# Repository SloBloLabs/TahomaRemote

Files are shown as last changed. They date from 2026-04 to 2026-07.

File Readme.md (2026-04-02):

# Tahoma Remote

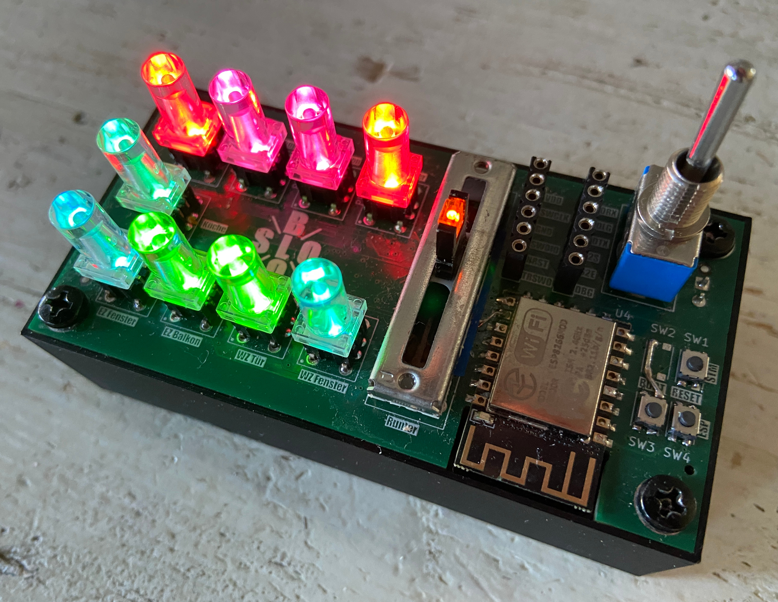
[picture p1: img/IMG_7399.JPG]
image info


## Overview
This device is an internet independent shutter control using the Tahoma Local API. At the same time, it serves as a proof of concept for integration of STM32F405 MCU with an ESP8266 using UART communication and Espressif AT command set.

Both hard and software are tailored to the requirements of my domestic Somfy roller shutter installation, consisting of 9 roller shutters controlled by a Tahoma Switch. The layout of buttons reflect the location of roller shutters looking top down to the flat for easy orientation. Adding/removing shutters to the setup is possible, but may require adaption of both hard and software.

This repository contains all ressources to build the device:
 * the firmware for the STM32 MCU
 * a script to upload ESP AT firmware to the ESP MCU
 * the board's KiCad design
 * a 3D model housing the board

## Operation
 * Switch the device on
 * During the startup sequence, Tahoma Remote
   * initializes communication to ESP
   * sets up WIFI connection
   * fetches current shutter states from Tahoma Switch
 * The button colours reflect the actual shutter closures of each motor in HSV colour space:
   * green = up
   * blue = 50%
   * red = closed
   * and any colour inbetween
 * Choose your target closure amount using the slider pot
 * Hit the buttons of corresponding shutters to execute the target closure command
 * While motors are moving, corresponding buttons are blinking
 * Motor status is updated each 1,5 seconds

## Highlights
As a proof of concept, these are the feature highlights of the project:
 * DMA driven UART communication between STM32F405 and ESP8266
 * Client side implementation of AT command set
 * Using Tahoma Local API. No internet required!
 * JSON stream parsing for memory efficient payload consumption (big up for the great [lwjson](https://github.com/MaJerle/lwjson.git) project!)
 * Highly capable RGB Led driver implementation using DMA, I2C and PCA9685PW driver chips
 * FreeRTOS for independent UI and communication threads
 * All firmware code written in plain C/C++ using STM32 LL (Low Level) API
 * Compact design
 * Battery powered

## Installation Notes
### Flashing ESP Firmware
 1. Install esptool using

        brew install esptool
 2. Go to https://github.com/espressif/esp-at/releases and find the link for the latest ESP8266 compatible AT firmware, such as

    [ESP-WROOM-02-AT-V2.3.0.0.zip](https://dl.espressif.com/esp-at/firmwares/esp8266/ESP-WROOM-02-AT-V2.3.0.0.zip)
 3. Download and extract the file into ESP subfolder.<br>
    Within the "factory" subfolder, the archive will contain the firmware binary file called "factory/factory_WROOM-02.bin"

 4. Connect a USB serial adapter such as FTDI Friend or Arduino Uno

        USB Serial Adapter            Tahoma Remote
                       GND ---------> GND
                        TX ---------> EDTX
                        RX ---------> EDRX

 5. Press and hold the ESP Boot button on Tahoma Remote and switch the device on. Then release the button again.
 6. Go to ESP subfolder and issue uploadATFW.sh script (check and apply correct settings regarding PORT and FWPATH variable!)

        ./uploadATFW.sh

    If the command is not executable, add respective rights to it:

        chmod u+x uploadATFW.sh
    
    The expected output looks something like this:

        esptool v5.1.0
        Connected to ESP8266 on /dev/cu.usbserial-XXX:
        Chip type:          ESP8266EX
        Features:           Wi-Fi, 160MHz
        Crystal frequency:  26MHz
        MAC:                e0:98:06:0a:71:a6
        
        Stub flasher running.
        
        Configuring flash size...
        Flash will be erased from 0x00000000 to 0x001fffff...
        Flash parameters set to 0x0241.
        Wrote 2097152 bytes (582385 compressed) at 0x00000000 in 54.0 seconds (310.8 kbit/s).
        Hash of data verified.
        
        Hard resetting via RTS pin...
    
### Flashing STM32 firmware
 1. Install VS Code
 2. Install STM32Cube Extensions for VS Code
 3. Add lwjson as submodule to the project

        git submodule add https://github.com/MaJerle/lwjson.git
        git submodule update --init
 4. Rename config_example.h to config.h and configure your local credentials and system information:
   * WIFI_SSID: your WIFI SSID
   * WIFI_PASSWD: your WIFI password
   * TAHOMA_HOST: the Tahoma Switch hostname, typically in the form 'gateway-\<box pin code\>.local'
   * TAHOMA_AUTH: the developer token generated within Somfy App
   * shutterConfigTable takes a set of roller shutters in the system (see TahomaManger.h for the structure of ShutterConfig entries)
 5. Configure and build the project using device STM32F405RGT6 and GCC toolchain in VSCode
    
    alternatively, if cmake and ninja are installed on the system, you can run these commands:

        cmake --preset Release
        cmake --build --preset Release
 6. Connect ST-Link to the SWO interface on Tahoma Remote
 7. Flash the firmware: Run and Debug and apply "STM32Cube: STLink GDB Server"

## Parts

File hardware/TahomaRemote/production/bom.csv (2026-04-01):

Designator | Footprint | Quantity | Value | LCSC Part #
BT1 | PinHeader_1x02_P2.54mm_Vertical | 1 | Battery
C1, C10, C12, C15, C16, C17, C18, C2, C21, C22, C23, C24, C25, C26, C4, C5, C6, C7, C8 | 0402 | 19 | 100n | C1525
C11, C29, C30 | 0402 | 3 | 1u | C52923
C19, C20 | 0402 | 2 | 2u2 | C12530
C27, C28, C3 | CP_EIA-3216-18_Kemet-A | 3 | 10u | C7171
C9 | 0402 | 1 | 10n | C15195
FB1 | 0603 | 1 | 120R@100MHz
J1 | PinSocket_1x06_P2.54mm_Vertical | 1 | SWO Connector
J2 | PinSocket_1x06_P2.54mm_Vertical | 1 | Conn_01x06_Socket
PB0, PB1, PB2, PB3, PB4, PB5, PB6, PB7, PB8 | TC002-N11AS2XT-RGB | 9 | TC002-N11AS2XT-RGB
R1, R2 | 0402 | 2 | 4k7 | C25900
R10, R12, R14, R17, R24, R26, R28, R30, R8 | 0402 | 9 | 470 | C25117
R11, R13, R15, R16, R18, R20, R21, R22, R23, R25, R27, R29, R31, R4, R5, R6, R7, R9 | 0402 | 18 | 220 | C25091
R19, R3, R32 | 0402 | 3 | 10k | C25744
R33 | 0402 | 1 | 49.9 | C25120
R35 | 0402 | 1 | 1k | C11702
S1 | Bourns_PTL20 | 1 | Bourns_PTL
SW1 | SW_Push_1P1T_NO_CK_KMR2 | 1 | ST Reset
SW3 | SW_Push_1P1T_NO_CK_KMR2 | 1 | ESP Boot Mode
SW4 | SW_Push_1P1T_NO_CK_KMR2 | 1 | ESP Reset
SW5 | SW_Toggle_MS500 | 1 | Power
U1, U2 | TSSOP-28_4.4x9.7mm_P0.65mm | 2 | PCA9685PW
U3 | LQFP-64_10x10mm_P0.5mm | 1 | STM32F405RGTx
U4 | ESP-12E | 1 | ESP-12F
U5 | TO-252-3_TabPin2 | 1 | LM1117DT-3.3

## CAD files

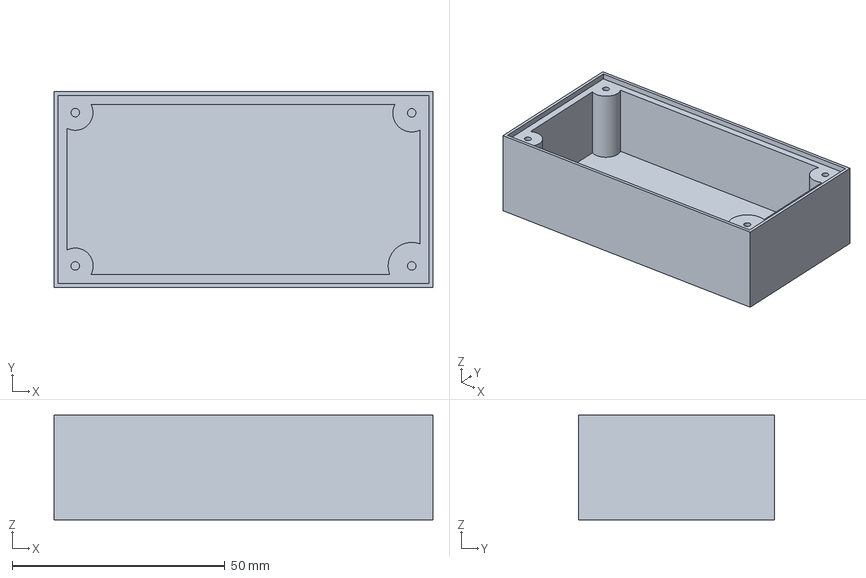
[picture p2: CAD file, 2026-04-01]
hardware/Case/TahomaRemoteCase-Body.3mf
89.0 x 46.0 x 24.6 mm

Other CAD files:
hardware/Case/TahomaRemoteCase.FCStd
hardware/Case/TahomaRemoteCase-Body.stl

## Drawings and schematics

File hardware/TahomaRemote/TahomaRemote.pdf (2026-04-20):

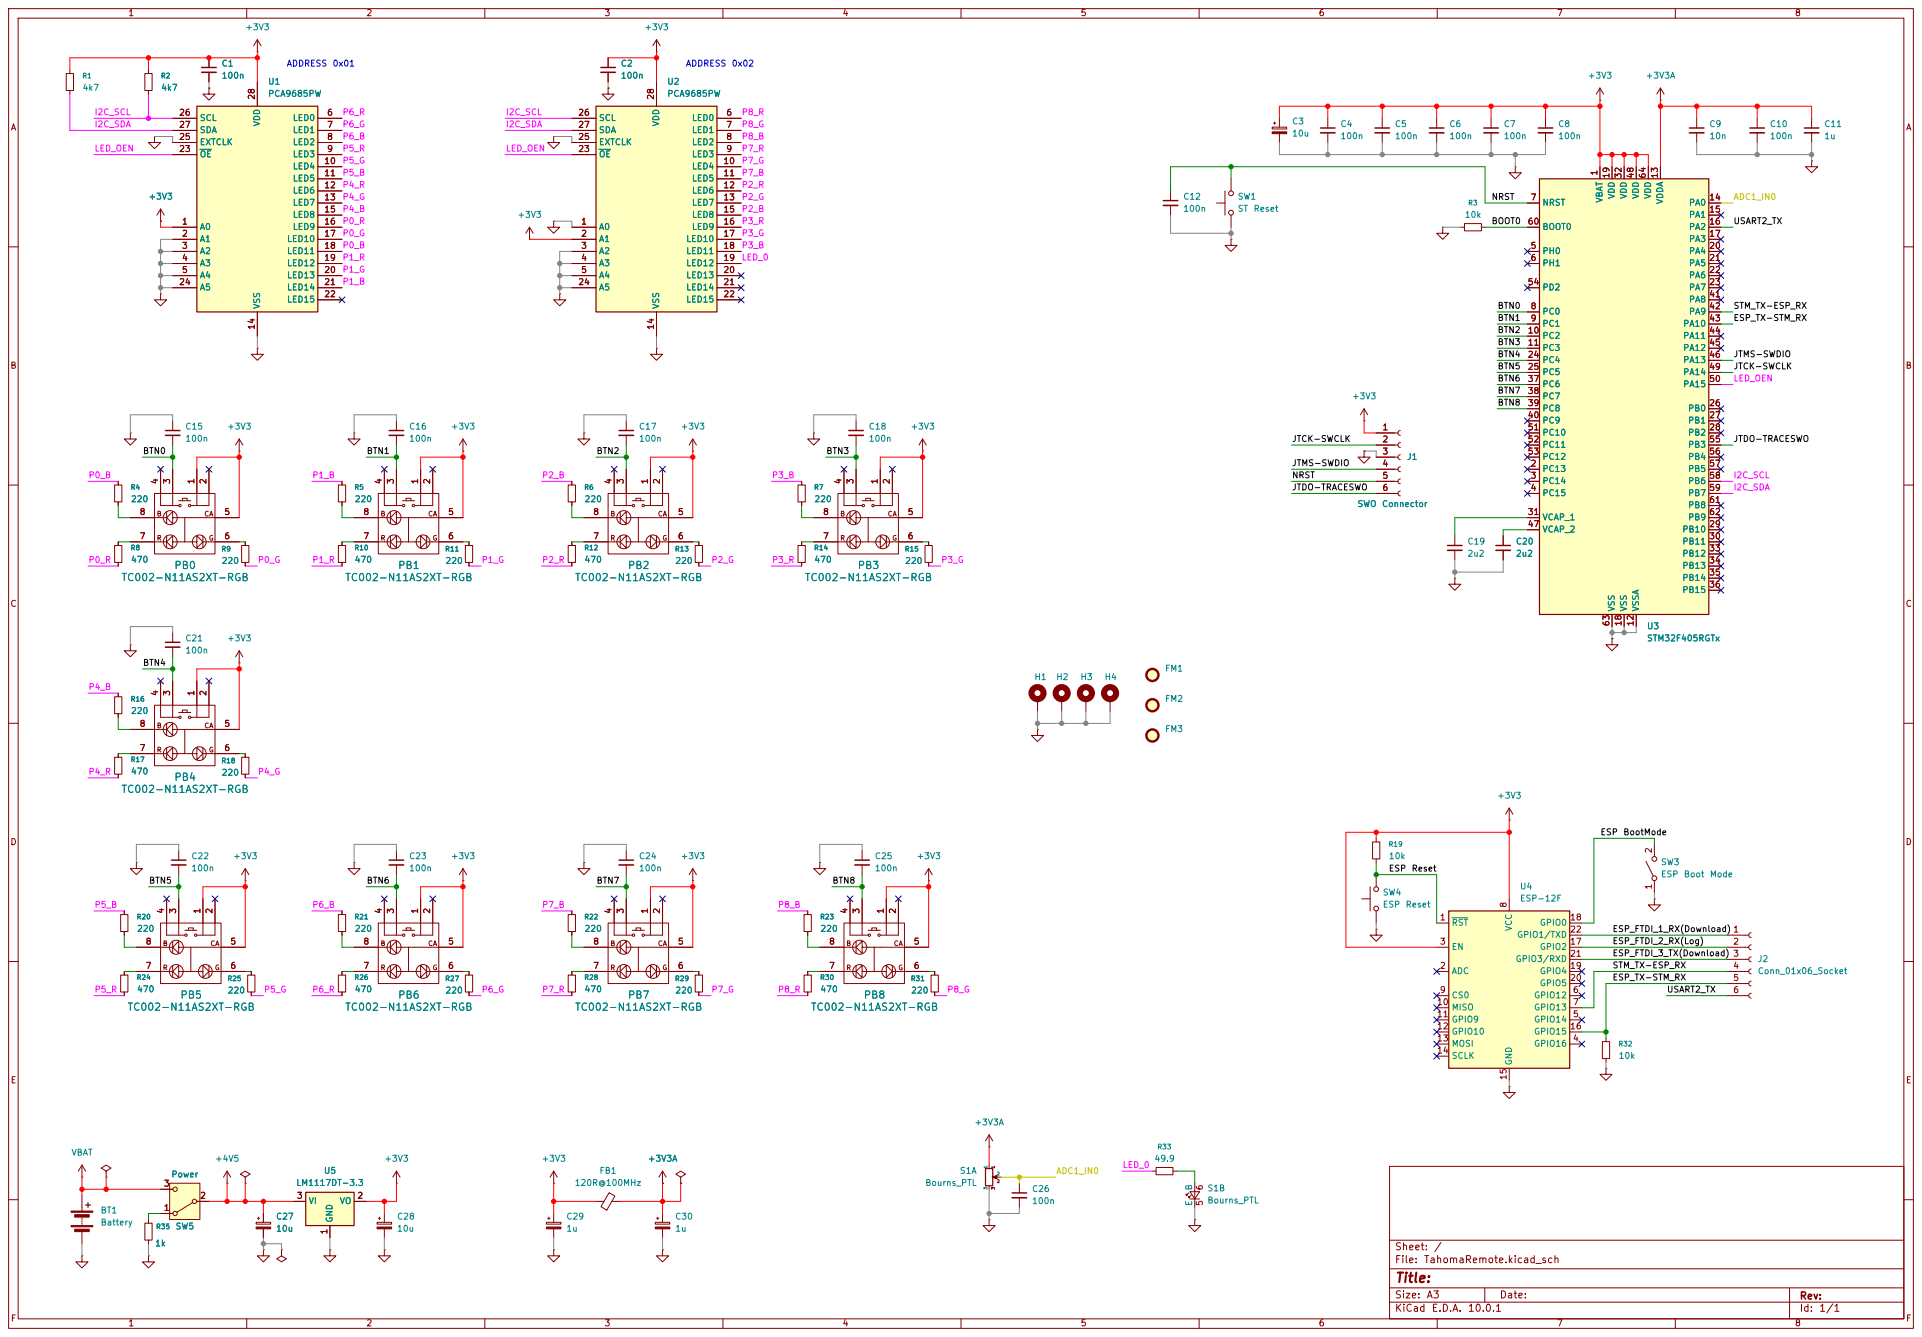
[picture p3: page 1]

Size: A3 | Rev: | F Date:
KiCad E.D.A. 10.0.1 | Id: 1/1

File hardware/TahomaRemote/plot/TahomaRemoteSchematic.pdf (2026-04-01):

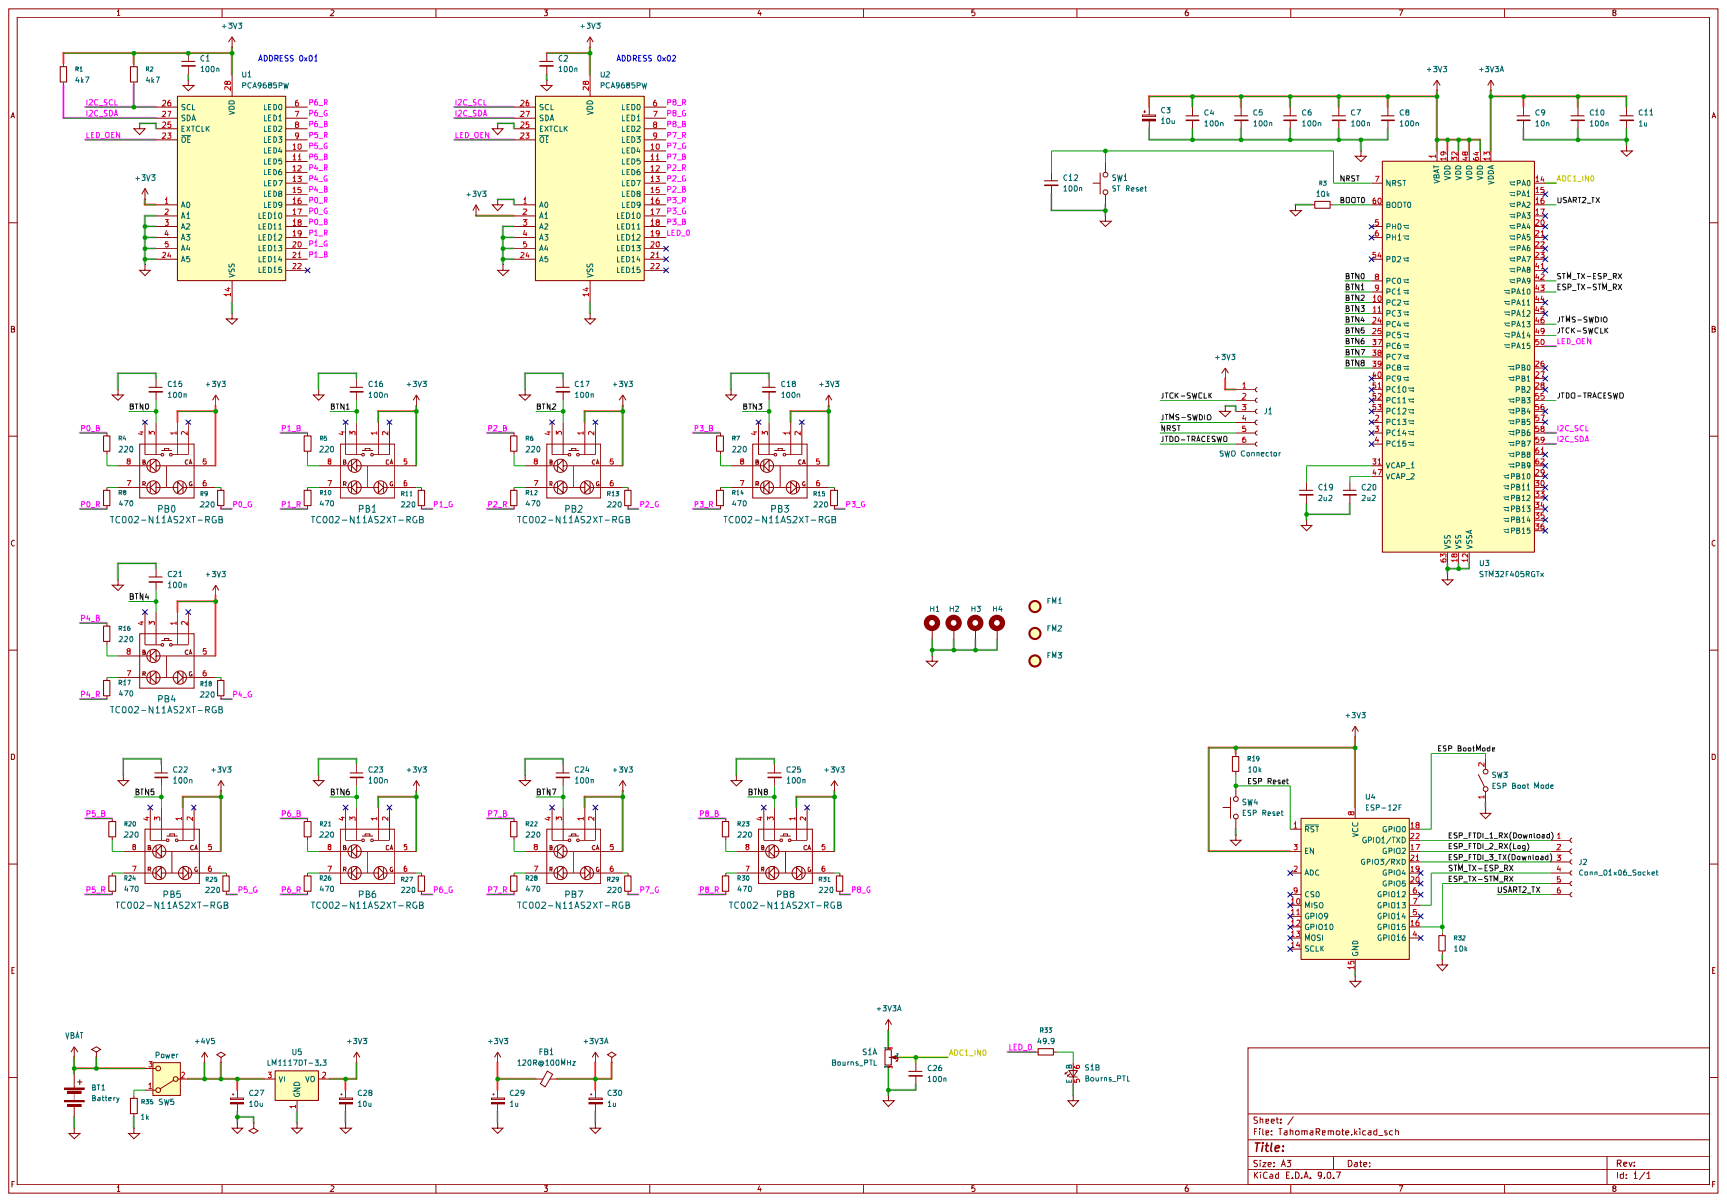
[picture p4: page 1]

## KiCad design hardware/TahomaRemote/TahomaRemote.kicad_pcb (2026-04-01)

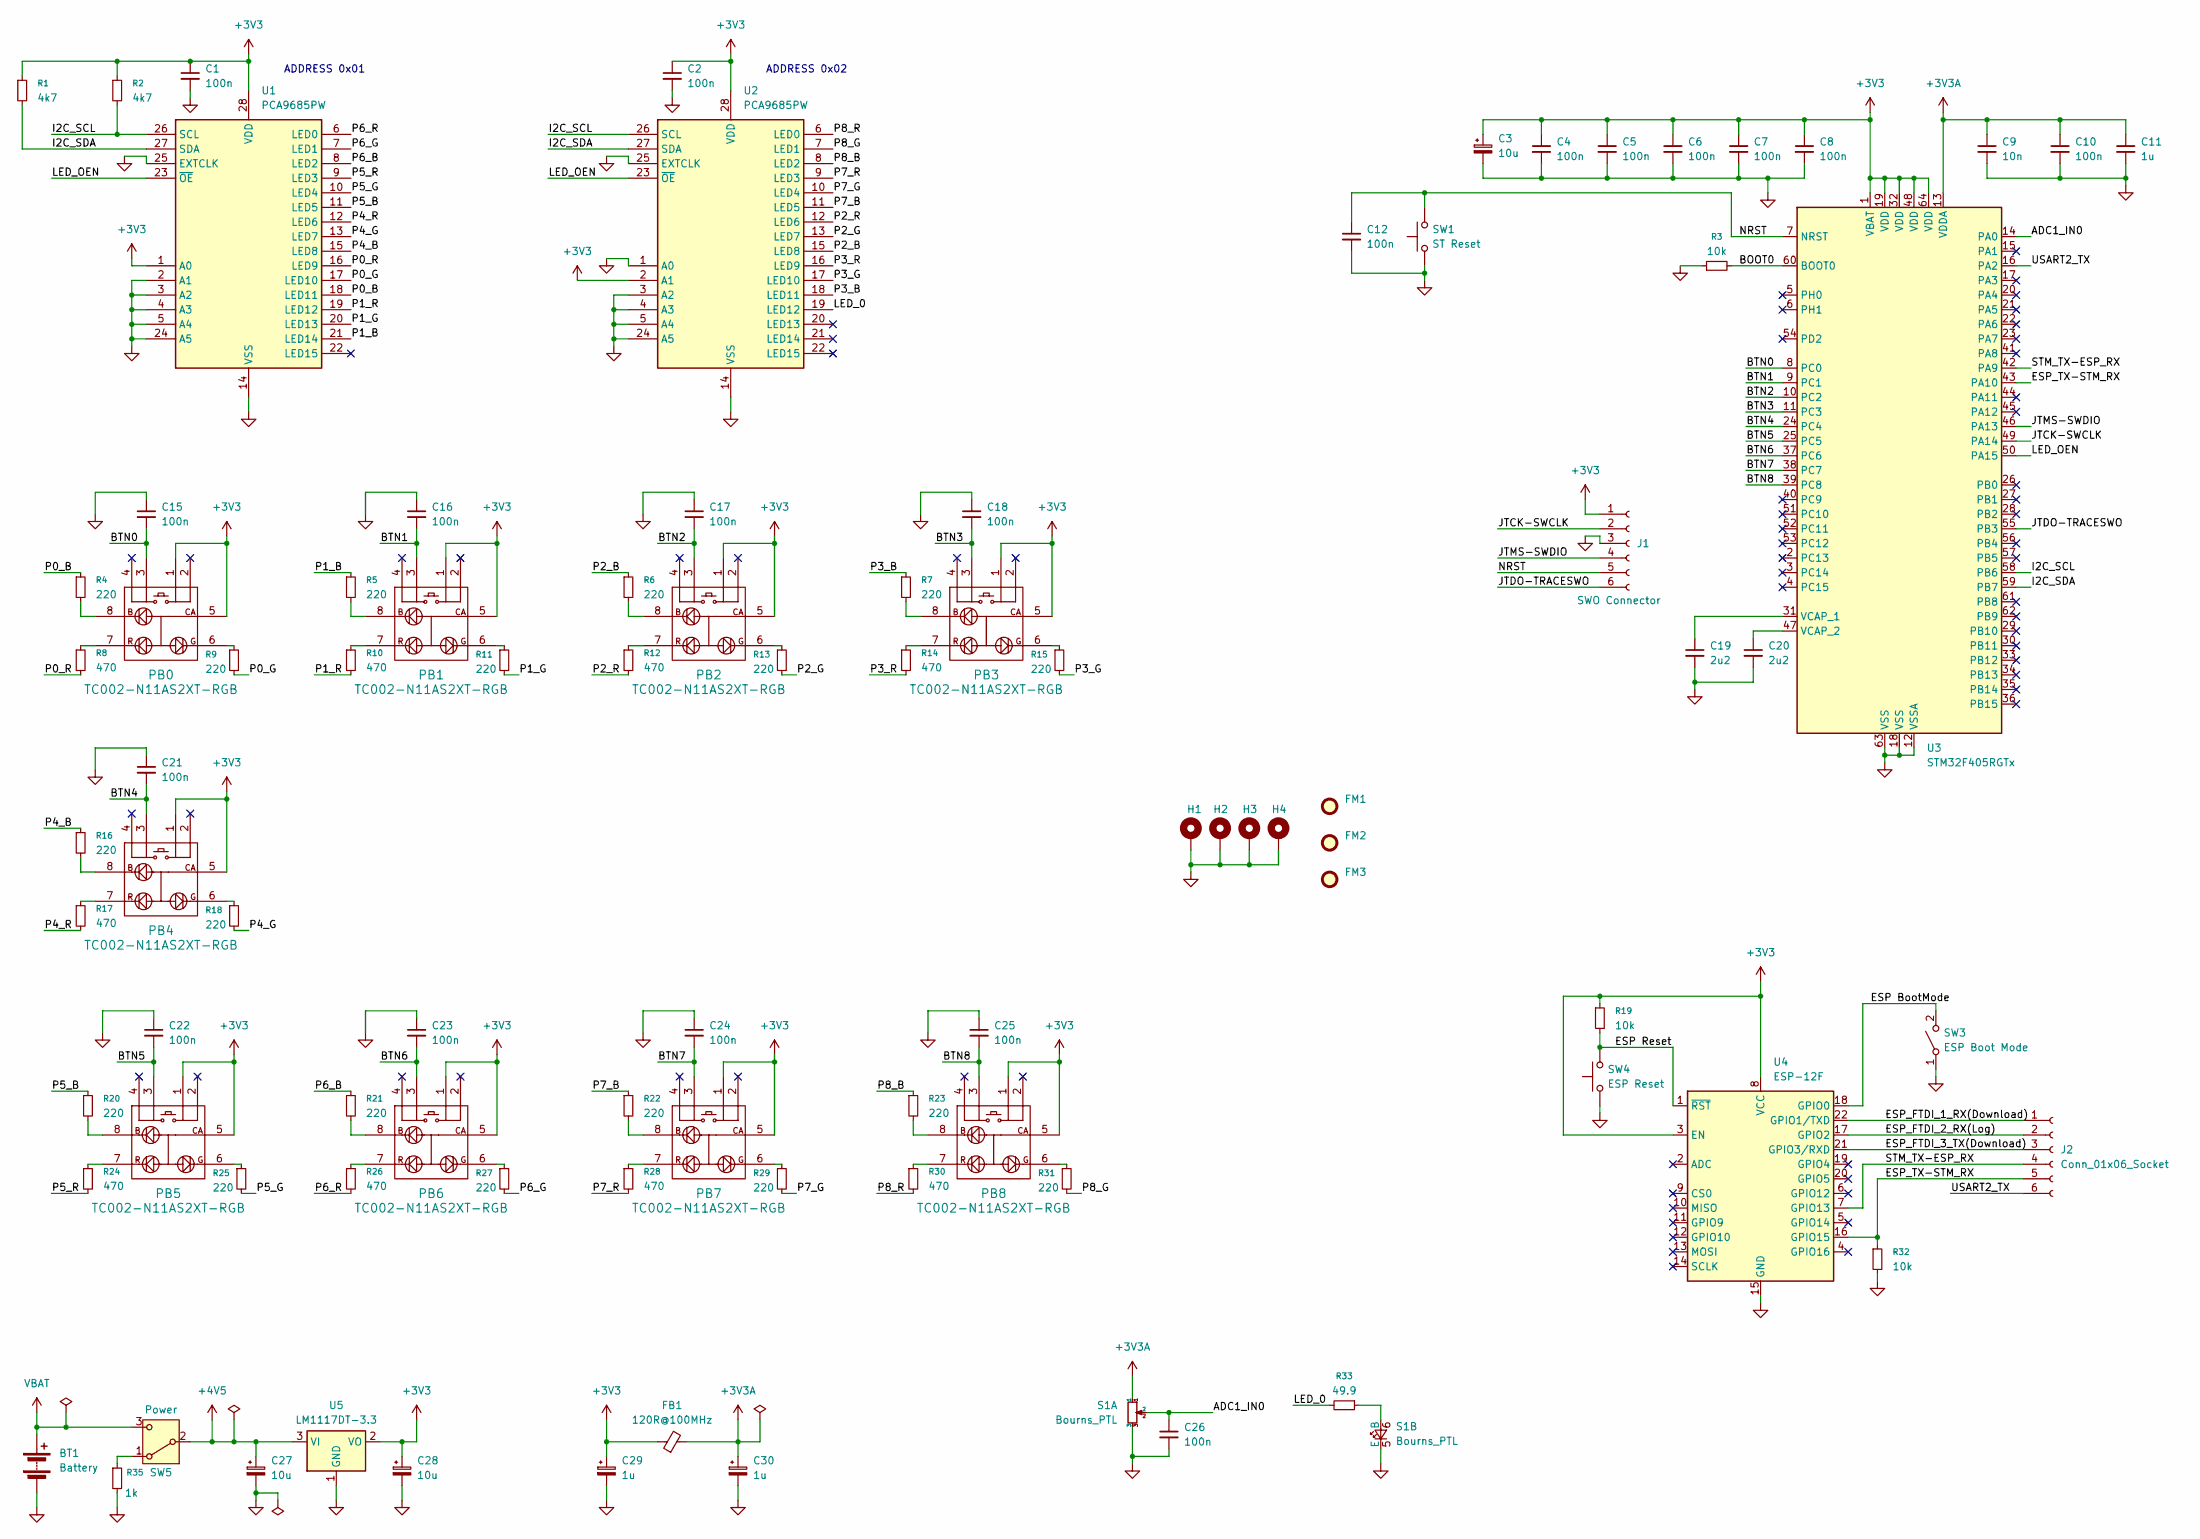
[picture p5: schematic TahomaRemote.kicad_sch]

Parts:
BT1: Battery; PinHeader_1x02_P2.54mm_Vertical
C1, C2, C4, C5, C6, C7, C8, C10, C12, C15, C16, C17, C18, C21, C22, C23, C24, C25, C26: 100n; C_0402_1005Metric; LCSC C1525
C3, C27, C28: 10u; CP_EIA-3216-18_Kemet-A; LCSC C7171
C9: 10n; C_0402_1005Metric; LCSC C15195
C11, C29, C30: 1u; C_0402_1005Metric; LCSC C52923
C19, C20: 2u2; C_0402_1005Metric; LCSC C12530
FB1: 120R@100MHz; L_0603_1608Metric
FM1, FM2, FM3: Fiducial; Fiducial_1mm_Mask2mm
H1, H2, H3, H4: MountingHole_Pad; MountingHole_3.2mm_M3_Pad_Via
J1: SWO Connector; PinSocket_1x06_P2.54mm_Vertical
J2: Conn_01x06_Socket; PinSocket_1x06_P2.54mm_Vertical
PB0, PB1, PB2, PB3, PB4, PB5, PB6, PB7, PB8: TC002-N11AS2XT-RGB
R1, R2: 4k7; R_0402_1005Metric; LCSC C25900
R3, R19, R32: 10k; R_0402_1005Metric; LCSC C25744
R4, R5, R6, R7, R9, R11, R13, R15, R16, R18, R20, R21, R22, R23, R25, R27, R29, R31: 220; R_0402_1005Metric; LCSC C25091
R8, R10, R12, R14, R17, R24, R26, R28, R30: 470; R_0402_1005Metric; LCSC C25117
R33: 49.9; R_0402_1005Metric; LCSC C25120
R35: 1k; R_0402_1005Metric; LCSC C11702
S1: Bourns_PTL; Bourns_PTL20
SW1: ST Reset; SW_Push_1P1T_NO_CK_KMR2
SW3: ESP Boot Mode; SW_Push_1P1T_NO_CK_KMR2
SW4: ESP Reset; SW_Push_1P1T_NO_CK_KMR2
SW5: Power; SW_Toggle_MS500
U1, U2: PCA9685PW; TSSOP-28_4.4x9.7mm_P0.65mm
U3: STM32F405RGTx; LQFP-64_10x10mm_P0.5mm
U4: ESP-12F; ESP-12E
U5: LM1117DT-3.3; TO-252-3_TabPin2

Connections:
+3V3: C1.1, C2.1, C3.1, C4.1, C5.1, C6.1, C7.1, C8.1, C28.1, C29.1, FB1.1, J1.1, PB0.1 (UP-A), PB0.5 (CA), PB1.1 (UP-A), PB1.5 (CA), PB2.1 (UP-A), PB2.5 (CA), PB3.1 (UP-A), PB3.5 (CA), PB4.1 (UP-A), PB4.5 (CA), PB5.1 (UP-A), PB5.5 (CA), PB6.1 (UP-A), PB6.5 (CA), PB7.1 (UP-A), PB7.5 (CA), PB8.1 (UP-A), PB8.5 (CA), R1.1, R2.1, R19.1, U1.1 (A0), U1.28 (VDD), U2.2 (A1), U2.28 (VDD), U3.1 (VBAT), U3.19 (VDD), U3.32 (VDD), U3.48 (VDD), U3.64 (VDD), U4.3 (EN), U4.8 (VCC), U5.2 (VO)
+3V3A: C9.1, C10.1, C11.1, C30.1, FB1.2, S1.1, U3.13 (VDDA)
+4V5: C27.1, SW5.2 (B), U5.3 (VI)
/ADC1_IN0: C26.1, S1.2, U3.14 (PA0)
/BOOT0: R3.2, U3.60 (BOOT0)
/BTN0: C15.2, PB0.3 (DOWN-A), U3.8 (PC0)
/BTN1: C16.2, PB1.3 (DOWN-A), U3.9 (PC1)
/BTN2: C17.2, PB2.3 (DOWN-A), U3.10 (PC2)
/BTN3: C18.2, PB3.3 (DOWN-A), U3.11 (PC3)
/BTN4: C21.2, PB4.3 (DOWN-A), U3.24 (PC4)
/BTN5: C22.2, PB5.3 (DOWN-A), U3.25 (PC5)
/BTN6: C23.2, PB6.3 (DOWN-A), U3.37 (PC6)
/BTN7: C24.2, PB7.3 (DOWN-A), U3.38 (PC7)
/BTN8: C25.2, PB8.3 (DOWN-A), U3.39 (PC8)
/ESP BootMode: SW3.2 (B), U4.18 (GPIO0)
/ESP Reset: R19.2, SW4.2, U4.1 (~RST)
/ESP_FTDI_1_RX(Download): J2.1, U4.22 (GPIO1/TXD)
/ESP_FTDI_2_RX(Log): J2.2, U4.17 (GPIO2)
/ESP_FTDI_3_TX(Download): J2.3, U4.21 (GPIO3/RXD)
/ESP_TX-STM_RX: J2.5, R32.1, U3.43 (PA10), U4.16 (GPIO15)
/I2C_SCL: R2.2, U1.26 (SCL), U2.26 (SCL), U3.58 (PB6)
/I2C_SDA: R1.2, U1.27 (SDA), U2.27 (SDA), U3.59 (PB7)
/JTCK-SWCLK: J1.2, U3.49 (PA14)
/JTDO-TRACESWO: J1.6, U3.55 (PB3)
/JTMS-SWDIO: J1.4, U3.46 (PA13)
/LED_0: R33.2, U2.19 (LED12)
/LED_OEN: U1.23 (~OE), U2.23 (~OE), U3.50 (PA15)
/NRST: C12.1, J1.5, SW1.2, U3.7 (NRST)
/P0_B: R4.1, U1.18 (LED11)
/P0_G: R9.2, U1.17 (LED10)
/P0_R: R8.2, U1.16 (LED9)
/P1_B: R5.1, U1.21 (LED14)
/P1_G: R11.2, U1.20 (LED13)
/P1_R: R10.2, U1.19 (LED12)
/P2_B: R6.1, U2.15 (LED8)
/P2_G: R13.2, U2.13 (LED7)
/P2_R: R12.2, U2.12 (LED6)
/P3_B: R7.1, U2.18 (LED11)
/P3_G: R15.2, U2.17 (LED10)
/P3_R: R14.2, U2.16 (LED9)
/P4_B: R16.1, U1.15 (LED8)
/P4_G: R18.2, U1.13 (LED7)
/P4_R: R17.2, U1.12 (LED6)
/P5_B: R20.1, U1.11 (LED5)
/P5_G: R25.2, U1.10 (LED4)
/P5_R: R24.2, U1.9 (LED3)
/P6_B: R21.1, U1.8 (LED2)
/P6_G: R27.2, U1.7 (LED1)
/P6_R: R26.2, U1.6 (LED0)
/P7_B: R22.1, U2.11 (LED5)
/P7_G: R29.2, U2.10 (LED4)
/P7_R: R28.2, U2.9 (LED3)
/P8_B: R23.1, U2.8 (LED2)
/P8_G: R31.2, U2.7 (LED1)
/P8_R: R30.2, U2.6 (LED0)
/STM_TX-ESP_RX: J2.4, U3.42 (PA9), U4.7 (GPIO13)
/USART2_TX: J2.6, U3.16 (PA2)
GND: BT1.2 (-), C1.2, C2.2, C3.2, C4.2, C5.2, C6.2, C7.2, C8.2, C9.2, C10.2, C11.2, C12.2, C15.1, C16.1, C17.1, C18.1, C19.2, C20.2, C21.1, C22.1, C23.1, C24.1, C25.1, C26.2, C27.2, C28.2, C29.2, C30.2, H1.1, H2.1, H3.1, H4.1, J1.3, R3.1, R32.2, R35.2, S1.3, S1.5 (E), SW1.1, SW3.1 (A), SW4.1, U1.2 (A1), U1.3 (A2), U1.4 (A3), U1.5 (A4), U1.14 (VSS), U1.24 (A5), U1.25 (EXTCLK), U2.1 (A0), U2.3 (A2), U2.4 (A3), U2.5 (A4), U2.14 (VSS), U2.24 (A5), U2.25 (EXTCLK), U3.12 (VSSA), U3.18 (VSS), U3.63 (VSS), U4.15 (GND), U5.1 (GND)
unnamed: PB0.8 (B), R4.2
unnamed: PB0.6 (G), R9.1
unnamed: PB0.7 (R), R8.1
unnamed: PB1.8 (B), R5.2
unnamed: PB1.6 (G), R11.1
unnamed: PB1.7 (R), R10.1
unnamed: PB2.8 (B), R6.2
unnamed: PB2.6 (G), R13.1
unnamed: PB2.7 (R), R12.1
unnamed: PB3.8 (B), R7.2
unnamed: PB3.6 (G), R15.1
unnamed: PB3.7 (R), R14.1
unnamed: PB4.8 (B), R16.2
unnamed: PB4.6 (G), R18.1
unnamed: PB4.7 (R), R17.1
unnamed: PB5.8 (B), R20.2
unnamed: PB5.6 (G), R25.1
unnamed: PB5.7 (R), R24.1
unnamed: PB6.8 (B), R21.2
unnamed: PB6.6 (G), R27.1
unnamed: PB6.7 (R), R26.1
unnamed: PB7.8 (B), R22.2
unnamed: PB7.6 (G), R29.1
unnamed: PB7.7 (R), R28.1
unnamed: PB8.8 (B), R23.2
unnamed: PB8.6 (G), R31.1
unnamed: PB8.7 (R), R30.1
unnamed: R33.1, S1.6 (B)
unnamed: R35.1, SW5.1 (A)
unnamed: C19.1, U3.31 (VCAP_1)
unnamed: C20.1, U3.47 (VCAP_2)
VBAT: BT1.1 (+), SW5.3 (C)

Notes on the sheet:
ADDRESS 0x01
ADDRESS 0x02

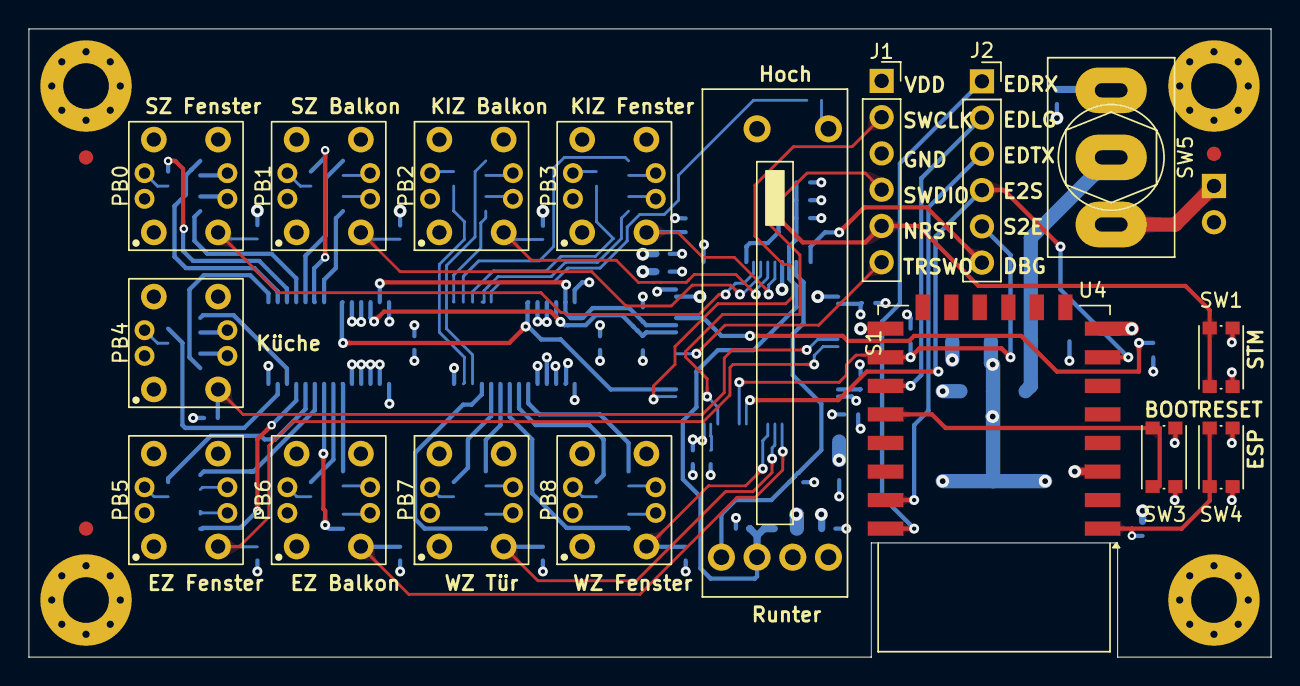
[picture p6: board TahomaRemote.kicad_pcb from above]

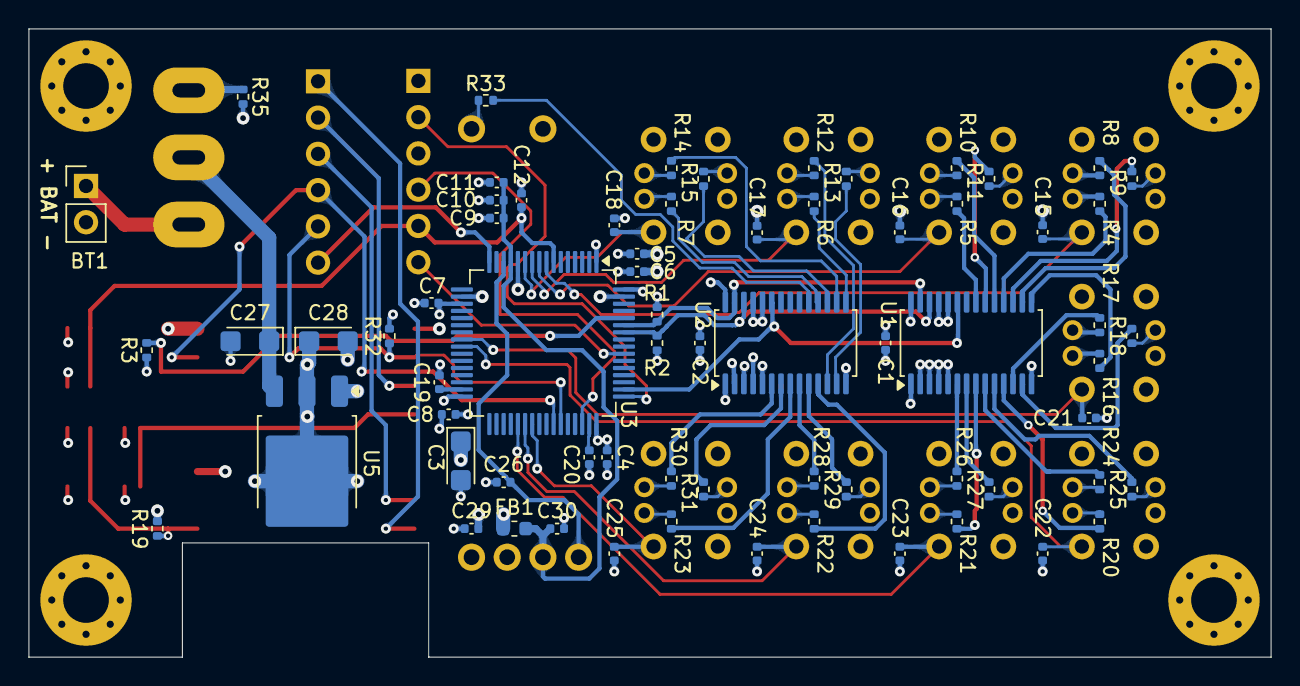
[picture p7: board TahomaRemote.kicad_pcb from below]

Board: 4 copper layers, 87.0 x 44.0 mm, 92 parts (68 on the bottom side), 90 nets.

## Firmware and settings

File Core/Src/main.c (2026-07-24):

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
/* Includes ------------------------------------------------------------------*/
#include "main.h"
#include "cmsis_os.h"
#include "adc.h"
#include "dma.h"
#include "i2c.h"
#include "usart.h"
#include "gpio.h"

/* USER CODE BEGIN Includes */
#include "Dbg.h"
/* USER CODE END Includes */

/* USER CODE BEGIN PD */
#define ESP_UART USART1
#define ESP_DMA DMA2
#define ESP_RX_DMA_STREAM LL_DMA_STREAM_5
#define ESP_TX_DMA_STREAM LL_DMA_STREAM_7
/* USER CODE END PD */


/* USER CODE BEGIN PV */
/* Buffer used for transmission */
#define RX_BUFFER_SIZE 1024
char rxBuffer[RX_BUFFER_SIZE];
volatile size_t readPtr = 0;
volatile size_t writePtr = 0;

#define TX_BUFFER_SIZE 1024
char txBuffer[TX_BUFFER_SIZE];
volatile uint8_t transmissionComplete = 1;

// Signaled from the UART RX ISR (USART idle-line / DMA half-transfer / DMA
// transfer-complete) whenever new bytes may be available. Lets nextChar()
// block briefly instead of busy-spinning while waiting for the ESP8266.
static osSemaphoreId_t rxDataSem = NULL;
/* USER CODE END PV */

void SystemClock_Config(void);
void MX_FREERTOS_Init(void);
/* USER CODE BEGIN PFP */
void     setupDMA(void);
int      StartTransfers(void);
uint8_t  Buffercmp8(uint8_t* pBuffer1, uint8_t* pBuffer2, uint8_t BufferLength);
/* USER CODE END PFP */

/**
  * @brief  The application entry point.
  * @retval int
  */
int main(void)
{

  /* MCU Configuration--------------------------------------------------------*/

  /* Reset of all peripherals, Initializes the Flash interface and the Systick. */
  HAL_Init();

  /* Configure the system clock */
  SystemClock_Config();

  /* Initialize all configured peripherals */
  MX_GPIO_Init();
  MX_DMA_Init();
  MX_USART1_UART_Init();
  MX_USART2_UART_Init();
  MX_ADC1_Init();
  MX_I2C1_Init();
  /* USER CODE BEGIN 2 */
  setupDMA();
  /* USER CODE END 2 */

  /* Init scheduler */
  osKernelInitialize();  /* Call init function for freertos objects (in cmsis_os2.c) */
  MX_FREERTOS_Init();

  /* Start scheduler */
  osKernelStart();

  /* We should never get here as control is now taken by the scheduler */

  /* Infinite loop */
  /* USER CODE BEGIN WHILE */
  while (1)
  {
    /* USER CODE END WHILE */

    /* USER CODE BEGIN 3 */
  }
  /* USER CODE END 3 */
}

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
/* USER CODE BEGIN 4 */
void setupDMA() {

  // Enable RX interrupts (HT, TC, Usart IDLE)
  LL_DMA_EnableIT_HT(ESP_DMA, ESP_RX_DMA_STREAM);
  LL_DMA_EnableIT_TC(ESP_DMA, ESP_RX_DMA_STREAM);
  LL_USART_EnableIT_IDLE(ESP_UART);

  // Enable DMA TX TC interrupts
  LL_DMA_EnableIT_TC(ESP_DMA, ESP_TX_DMA_STREAM);

  // Configure TX DMA
  LL_DMA_SetPeriphAddress(ESP_DMA, ESP_TX_DMA_STREAM, LL_USART_DMA_GetRegAddr(USART1));

  // start DMA reception
  LL_DMA_SetPeriphAddress(ESP_DMA, ESP_RX_DMA_STREAM, LL_USART_DMA_GetRegAddr(USART1));
  LL_DMA_SetMemoryAddress(ESP_DMA, ESP_RX_DMA_STREAM, (uint32_t)rxBuffer);
  LL_DMA_SetDataLength(ESP_DMA, ESP_RX_DMA_STREAM, sizeof(rxBuffer));
  LL_USART_EnableDMAReq_RX(ESP_UART);
  //LL_USART_ClearFlag_TC(USART1);
  LL_DMA_EnableStream(ESP_DMA, ESP_RX_DMA_STREAM);

}

void sendCommand(const char* buf, size_t len) {
  TRACE_LOG("sendCommand: %.*s with length %d\n", len, buf, len);
  if(len >= TX_BUFFER_SIZE) {
    USER_LOG("Command too long for TR Buffer %d", len);
    return;
  }
  
  while(transmissionComplete != 1);
  memcpy(txBuffer, buf, len);

  // DMA transfer
  LL_DMA_SetMemoryAddress(ESP_DMA, ESP_TX_DMA_STREAM, (uint32_t)txBuffer);
  LL_DMA_SetDataLength(ESP_DMA, ESP_TX_DMA_STREAM, len);
  LL_USART_EnableDMAReq_TX(ESP_UART);
  LL_USART_ClearFlag_TC(ESP_UART);
  LL_DMA_EnableStream(ESP_DMA, ESP_TX_DMA_STREAM);
  transmissionComplete = 0;
}

size_t available() {
  if(writePtr >= readPtr) {
    return writePtr - readPtr;
  } else {
    return (sizeof(rxBuffer) - readPtr) + writePtr;
  }
}

void uartRxSemInit(void) {
  rxDataSem = osSemaphoreNew(1, 0, NULL);
}

char nextChar() {
  if(!available()) {
    // Block briefly for new data instead of busy-spinning; rxDataSem is
    // released by uartRxCallback() when the ISR observes new bytes. Bounded
    // wait keeps callers' own timeout/elapsed-time checks working as before.
    if(rxDataSem != NULL) {
      osSemaphoreAcquire(rxDataSem, 500);
    }
    if(!available()) {
      return 0;
    }
  }
  char c = rxBuffer[readPtr++];
  if(readPtr == RX_BUFFER_SIZE) {
    readPtr = 0;
  }
  return c;
}

void uartRxCallback() {
  writePtr = sizeof(rxBuffer) - LL_DMA_GetDataLength(DMA2, LL_DMA_STREAM_5);
  if(rxDataSem != NULL) {
    osSemaphoreRelease(rxDataSem);
  }
}

void uartTxCompleteCallback() {
  transmissionComplete = 1;
}
/* USER CODE END 4 */

/**
  * @brief  Period elapsed callback in non blocking mode
  * @note   This function is called  when TIM1 interrupt took place, inside
  * HAL_TIM_IRQHandler(). It makes a direct call to HAL_IncTick() to increment
  * a global variable "uwTick" used as application time base.
  * @param  htim : TIM handle
  * @retval None
  */
void HAL_TIM_PeriodElapsedCallback(TIM_HandleTypeDef *htim)
{
  if (htim->Instance == TIM1)
  {
    HAL_IncTick();
  }
}

/**
  * @brief  This function is executed in case of error occurrence.
  * @retval None
  */
void Error_Handler(void)
{
  /* USER CODE BEGIN Error_Handler_Debug */
  /* User can add his own implementation to report the HAL error return state */
  __disable_irq();
  while (1)
  {
  }
  /* USER CODE END Error_Handler_Debug */
}
#ifdef USE_FULL_ASSERT
/**
  * @brief  Reports the name of the source file and the source line number
  *         where the assert_param error has occurred.
  * @param  file: pointer to the source file name
  * @param  line: assert_param error line source number
  * @retval None
  */
void assert_failed(uint8_t *file, uint32_t line)
{
  /* USER CODE BEGIN 6 */
  /* User can add his own implementation to report the file name and line number,
     ex: printf("Wrong parameters value: file %s on line %d\r\n", file, line) */
  /* USER CODE END 6 */
}
#endif /* USE_FULL_ASSERT */

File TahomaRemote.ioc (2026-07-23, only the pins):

Mcu.UserName=STM32F405RGTx
PA0-WKUP.Signal=ADCx_IN0
PA10.Signal=USART1_RX
PA13.Signal=SYS_JTMS-SWDIO
PA14.Signal=SYS_JTCK-SWCLK
PA15.GPIO_Label=LED_OEN
PA15.Signal=GPIO_Output
PA2.Signal=USART2_TX
PA3.GPIO_Label=LED
PA3.Signal=GPIO_Output
PA9.Signal=USART1_TX
PB3.Signal=SYS_JTDO-SWO
PB6.Signal=I2C1_SCL
PB7.Signal=I2C1_SDA
PC0.GPIO_Label=BTN0
PC0.Signal=GPXTI0
PC1.GPIO_Label=BTN1
PC1.Signal=GPXTI1
PC2.GPIO_Label=BTN2
PC2.Signal=GPXTI2
PC3.GPIO_Label=BTN3
PC3.Signal=GPXTI3
PC4.GPIO_Label=BTN4
PC4.Signal=GPXTI4
PC5.GPIO_Label=BTN5
PC5.Signal=GPXTI5
PC6.GPIO_Label=BTN6
PC6.Signal=GPXTI6
PC7.GPIO_Label=BTN7
PC7.Signal=GPXTI7
PC8.GPIO_Label=BTN8
PC8.Signal=GPXTI8
PH0-OSC_IN.Signal=RCC_OSC_IN
PH1-OSC_OUT.Signal=RCC_OSC_OUT

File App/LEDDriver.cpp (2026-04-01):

#include "LEDDriver.h"
#include "System.h"
#include "math.h"
#include "Dbg.h"
#include "Utils.h"
#include "cmsis_os2.h"

#define USE_DMA    1
#define LED_I2C    I2C1
#define DMA_STREAM LL_DMA_STREAM_6

// http://stefanfrings.de/stm32/stm32f1.html#i2c
// https://community.st.com/s/question/0D50X00009bLPuwSAG/busy-bus-after-i2c-reading

void LEDDriver::init() {
    //LL_I2C_Enable(LED_I2C); // -> already called by LL_I2C_Init

    if(USE_DMA) {
        //LL_I2C_EnableIT_EVT(LED_I2C);
        //LL_I2C_EnableIT_ERR(LED_I2C);

        LL_DMA_DisableStream(DMA1, DMA_STREAM);
    }

    _chipAddressArray = {1, 2};

    _ledTypeArray[0] = {
        COMMON_ANODE,
        COMMON_ANODE,
        COMMON_ANODE,
        COMMON_ANODE,
        COMMON_ANODE,
        COMMON_ANODE,
        COMMON_ANODE,
        COMMON_ANODE,
        COMMON_ANODE,
        COMMON_ANODE,
        COMMON_ANODE,
        COMMON_ANODE,
        COMMON_ANODE,
        COMMON_ANODE,
        COMMON_ANODE,
        EMPTY};
    
    _ledTypeArray[1] = {
        COMMON_ANODE,
        COMMON_ANODE,
        COMMON_ANODE,
        COMMON_ANODE,
        COMMON_ANODE,
        COMMON_ANODE,
        COMMON_ANODE,
        COMMON_ANODE,
        COMMON_ANODE,
        COMMON_ANODE,
        COMMON_ANODE,
        COMMON_ANODE,
        COMMON_CATHODE,
        EMPTY,
        EMPTY,
        EMPTY};
    
    _transmissionBusy = 0;
    _curChip = 0;

    for(uint32_t chip = 0; chip < NUM_PWM_LED_CHIPS; ++chip) {
        resetChip(chip);
    }
    
    clear();

    // Tie to ground! Disabling brings common cathode LEDs full on.
    ledEnable();
}

void LEDDriver::process() {
    if(_transmissionBusy) {
        return;
    }

    //_pwmLeds[0][0][LED_ON] = 0xFFF; // LED 1 RED
    //_pwmLeds[0][0][LED_OFF] = 0x1000; // LED 1 RED
    //_pwmLeds[0][1][LED_OFF] = 0x0FFF; // LED 1 GREEN
    //_pwmLeds[0][2][LED_OFF] = 0x0FFF; // LED 1 BLUE
    //_pwmLeds[0][3][LED_OFF] = 0x0FFF; // LED 2 RED
    //_pwmLeds[0][4][LED_OFF] = 0x0FFF; // LED 2 GREEN
    //_pwmLeds[0][5][LED_OFF] = 0x0FFF; // LED 2 BLUE
    //_pwmLeds[0][6][LED_OFF] = 0x0FFF; // LED 3 RED
    //_pwmLeds[0][7][LED_OFF] = 0x0FFF; // LED 3 GREEN
    //_pwmLeds[0][8][LED_OFF] = 0x0FFF; // LED 3 BLUE
    //_pwmLeds[0][9][LED_OFF] = 0x0FFF; // LED 4 RED
    //_pwmLeds[0][10][LED_OFF] = 0x0FFF; // LED 4 GREEN
    //_pwmLeds[0][11][LED_OFF] = 0x0FFF; // LED 4 BLUE
    //_pwmLeds[0][12][LED_ON] = 0x1000; // LED 5 RED
    //_pwmLeds[0][12][LED_OFF] = 0xFFF; // LED 5 RED
    //_pwmLeds[0][13][LED_ON] = 0x1FFF; // LED 5 GREEN
    //_pwmLeds[0][13][LED_OFF] = 0x0; // LED 5 GREEN
    //_pwmLeds[0][14][LED_ON] = 0x1FFF; // LED 5 BLUE
    //_pwmLeds[0][14][LED_OFF] = 0x0; // LED 5 BLUE
    //_pwmLeds[0][15][LED_OFF] = 0x0FFF; // EMPTY
    //_pwmLeds[1][0][LED_ON] = 0x1FFF; // LED 6 RED
    //_pwmLeds[1][0][LED_OFF] = 0x0; // LED 6 RED
    //_pwmLeds[1][1][LED_ON] = 0x1FFF; // LED 6 GREEN
    //_pwmLeds[1][1][LED_OFF] = 0x0; // LED 6 GREEN
    //_pwmLeds[1][2][LED_ON] = 0x1FFF; // LED 6 BLUE
    //_pwmLeds[1][2][LED_OFF] = 0x0; // LED 6 BLUE
    //_pwmLeds[1][3][LED_ON] = 0x1FFF; // LED 7 RED
    //_pwmLeds[1][3][LED_OFF] = 0x0; // LED 7 RED
    //_pwmLeds[1][4][LED_ON] = 0x1FFF; // LED 7 GREEN
    //_pwmLeds[1][4][LED_OFF] = 0x0; // LED 7 GREEN
    //_pwmLeds[1][5][LED_ON] = 0x1FFF; // LED 7 BLUE
    //_pwmLeds[1][5][LED_OFF] = 0x0; // LED 7 BLUE
    //_pwmLeds[1][6][LED_ON] = 0x1FFF; // LED 8 RED
    //_pwmLeds[1][6][LED_OFF] = 0x0; // LED 8 RED
    //_pwmLeds[1][7][LED_ON] = 0x1FFF; // LED 8 GREEN
    //_pwmLeds[1][7][LED_OFF] = 0x0; // LED 8 GREEN
    //_pwmLeds[1][8][LED_ON] = 0x1FFF; // LED 8 BLUE
    //_pwmLeds[1][8][LED_OFF] = 0x0; // LED 8 BLUE

    if(USE_DMA) {
        _curChip = 0;
        _transmissionBusy = 1;
        writeRegistersDMA(_curChip, PCA9685_LED0, reinterpret_cast<uint8_t*>(_pwmLeds[_curChip]), 15 << 2);
    } else {
        ErrorStatus status;
        for(_curChip = 0; _curChip < NUM_PWM_LED_CHIPS; ++_curChip) {
            status = writeRegisters(_curChip, PCA9685_LED0, reinterpret_cast<uint8_t*>(_pwmLeds[_curChip]), 15 << 2);
            if(status == ERROR) {
                DEBUG_LOG("\n[LEDDriver.process] error writing to register");
            }
        }
    }
}

void LEDDriver::notifyTxComplete() {
    // DBG("LED Tx Complete!");
    stopTransfer();
    LL_DMA_DisableStream(DMA1, DMA_STREAM);
    if(++_curChip < NUM_PWM_LED_CHIPS) {
        writeRegistersDMA(_curChip, PCA9685_LED0, reinterpret_cast<uint8_t*>(_pwmLeds[_curChip]), 15 << 2);
    } else {
        _transmissionBusy = 0;
    }
}

void LEDDriver::notifyTxError() {
    DEBUG_LOG("\n[LEDDriver.notifyTxError] LED Tx Error!");
    NVIC_DisableIRQ(DMA1_Stream7_IRQn);
}

void LEDDriver::clear() {
    if(_transmissionBusy) {
        return;
    }

    for(uint32_t chip = 0; chip < NUM_PWM_LED_CHIPS; ++chip) {
        for(uint32_t led = 0; led < NUM_LEDS_PER_CHIP; ++led) {
            _pwmLeds[chip][led][LED_ON] = _ledTypeArray[chip][led] == COMMON_CATHODE ? 0x1000 : 0;
            _pwmLeds[chip][led][LED_OFF] = 0;
        }
    }
}

//|---------------|---------------------------------|------------------------------------------|
//|               |      RGB LED / CommonCathode    |     TC002-N11AS2XT-RGB / CommonAnode     |
//|---------------|---------------------------------|------------------------------------------|
//|               | LED_ON                | LED_OFF | LED_ON                         | LED_OFF |
//|---------------|-----------------------|---------|--------------------------------|---------|
//| LED full off  | 0x1XXX                | 0xX     | 0x0                            | 0x0     |
//| LED full on   | 0x0                   | 0x0     | 0xX                            | 0x1XXX  | <- not implemented
//| LED 1/4095    | 0x0                   | 0xFFF   | 0x0                            | 0x1     |
//| LED 4094/4095 | 0x0                   | 0x1     | 0x0                            | 0xFFF   |

void LEDDriver::setSingleLED(uint8_t led, uint16_t brightness) {
    while(_transmissionBusy);

    if(led < NUM_PWM_LED_CHIPS * NUM_LEDS_PER_CHIP) {
        uint32_t chipNumber = led / NUM_LEDS_PER_CHIP;
        led -= chipNumber * NUM_LEDS_PER_CHIP;
        if(_ledTypeArray[chipNumber][led] == COMMON_CATHODE) {
            if(brightness == 0) {
                _pwmLeds[chipNumber][led][LED_ON]= 0x1000;
            } else {
                _pwmLeds[chipNumber][led][LED_ON]= 0x0;
                _pwmLeds[chipNumber][led][LED_OFF]= 0x1000 - brightness;
            }
        } else {
            _pwmLeds[chipNumber][led][LED_OFF]= brightness;
        }
    }
}

void LEDDriver::setColourRGB(uint8_t colourLED, float r, float g, float b) {
    uint8_t startLed = colourLED * 3 + floor(colourLED / 5);
    setSingleLED(startLed++, MAX_R_VALUE * r);
    setSingleLED(startLed++, MAX_G_VALUE * g);
    setSingleLED(startLed  , MAX_B_VALUE * b);
}
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

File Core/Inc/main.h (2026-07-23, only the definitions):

#define BTN0_Pin LL_GPIO_PIN_0
#define BTN0_GPIO_Port GPIOC
#define BTN0_EXTI_IRQn EXTI0_IRQn
#define BTN1_Pin LL_GPIO_PIN_1
#define BTN1_GPIO_Port GPIOC
#define BTN1_EXTI_IRQn EXTI1_IRQn
#define BTN2_Pin LL_GPIO_PIN_2
#define BTN2_GPIO_Port GPIOC
#define BTN2_EXTI_IRQn EXTI2_IRQn
#define BTN3_Pin LL_GPIO_PIN_3
#define BTN3_GPIO_Port GPIOC
#define BTN3_EXTI_IRQn EXTI3_IRQn
#define LED_Pin LL_GPIO_PIN_3
#define LED_GPIO_Port GPIOA
#define BTN4_Pin LL_GPIO_PIN_4
#define BTN4_GPIO_Port GPIOC
#define BTN4_EXTI_IRQn EXTI4_IRQn
#define BTN5_Pin LL_GPIO_PIN_5
#define BTN5_GPIO_Port GPIOC
#define BTN5_EXTI_IRQn EXTI9_5_IRQn
#define BTN6_Pin LL_GPIO_PIN_6
#define BTN6_GPIO_Port GPIOC
#define BTN6_EXTI_IRQn EXTI9_5_IRQn
#define BTN7_Pin LL_GPIO_PIN_7
#define BTN7_GPIO_Port GPIOC
#define BTN7_EXTI_IRQn EXTI9_5_IRQn
#define BTN8_Pin LL_GPIO_PIN_8
#define BTN8_GPIO_Port GPIOC
#define BTN8_EXTI_IRQn EXTI9_5_IRQn
#define LED_OEN_Pin LL_GPIO_PIN_15
#define LED_OEN_GPIO_Port GPIOA

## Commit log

2026-04-01 initial upload
    [TahomaRemote.kicad_pcb, TahomaRemote.kicad_sch, TahomaRemoteCase-Body.3mf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]
2026-04-20 Add schematic pdf

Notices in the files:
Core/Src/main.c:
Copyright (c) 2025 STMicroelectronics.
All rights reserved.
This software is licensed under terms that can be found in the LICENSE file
